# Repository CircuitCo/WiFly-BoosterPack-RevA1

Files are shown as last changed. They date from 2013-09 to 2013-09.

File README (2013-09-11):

The WiFly BoosterPack equips your Launchpad with the ability to connect to 802.11b/g wireless networks.  The design uses the Launchpad's UART hardware to interface to Roving Network's RN171XV ultra-low power embedded TCP/IP module.  An external antenna can be attached via a standard RP-SMA connector. Due to its small form factor and extremely low power consumption, it is perfect for mobile wireless applications such as asset monitoring, sensors, and portable battery operated devices. The WiFly BoosterPack is compatible with the MSP430 LaunchPad and Tiva C LaunchPad (previously Stellaris). This board is designed by Sakoman Inc. For more information on the designer please visit http://www.sakoman.com/.

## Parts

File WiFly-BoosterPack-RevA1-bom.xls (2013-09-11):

WIFLY BOOSTERPACK REV A1
QTY | REF DES | DESCRIPTION | PACKAGE | MAN | MAN P/N | VENDOR | VENDOR P/N
1 | R1 | RES 100K OHM 1/4W 5% CARBON FILM | thru-hole | STACKPOLE | CF14JT100K | DIGI-KEY | CF14JT100KTR-ND
2 | J1/3, J4/2 | 2.54 FEMALE HEADER DIP STRAIGHT HEIGHT=8.5MM 2X10 DIP=10.5mm GOLD | 2x10 0.1 thru-hole | MLE | SSHQ-110-D-08-F-LF
1 | J5 | CONN HEADER 8POS .100 STR 30AU | 2x4 0.1 thru-hole | FCI | 68602-108HLF | DIGI-KEY | 609-3362-ND
1 | U1 | WiFi / 802.11 Modules WIFI MOD FOR EXISTNG 802.15.4 W/ RP-SMA ANT | thru- hole | ROVING NETWORKS | RN-171-XV-S | MOUSER | 765-RN-XV-S
1 |  | PCB SI-10003 Rev A, 2 layers 0.062" FR4 1 oz copper, red SM, HASL

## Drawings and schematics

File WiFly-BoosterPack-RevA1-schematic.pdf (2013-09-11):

A

A

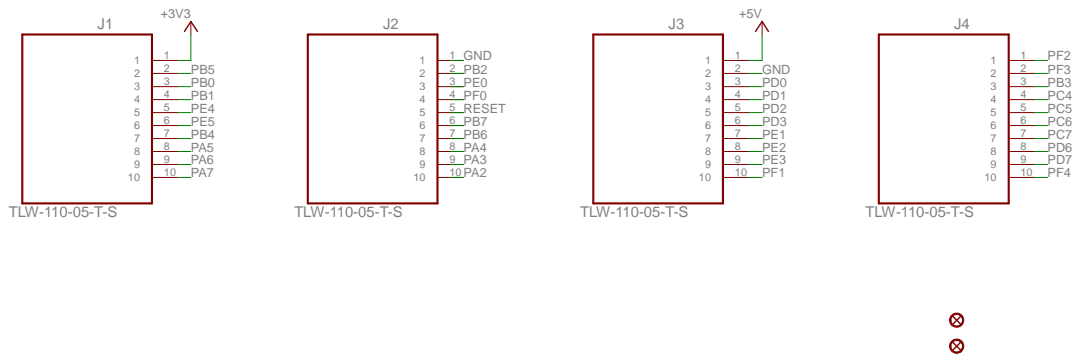
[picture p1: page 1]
TLW-110-05-T-S; GND; PE0 PF0 RESET PB7 PB6 PA4 PA3 PA2

A

A

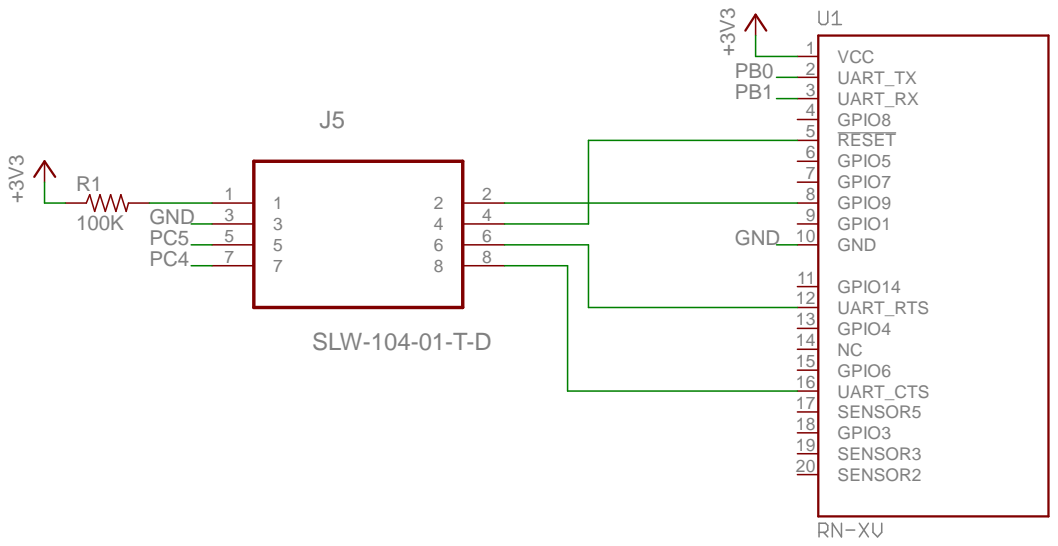
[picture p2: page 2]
SLW-104-01-T-D; VCC 1; GPIO5 6; RESET 5; GPIO7 7; UART_TX 2; GPIO8 4; GPIO9 8; GPIO3 18; UART_RTS 12; GPIO1 9; UART_RX 3; SENSOR5 17; GPIO14 11; GND 10; GPIO4 13 NC 14 GPIO6 15 UART_CTS 16; SENSOR3 19 SENSOR2 20; GND

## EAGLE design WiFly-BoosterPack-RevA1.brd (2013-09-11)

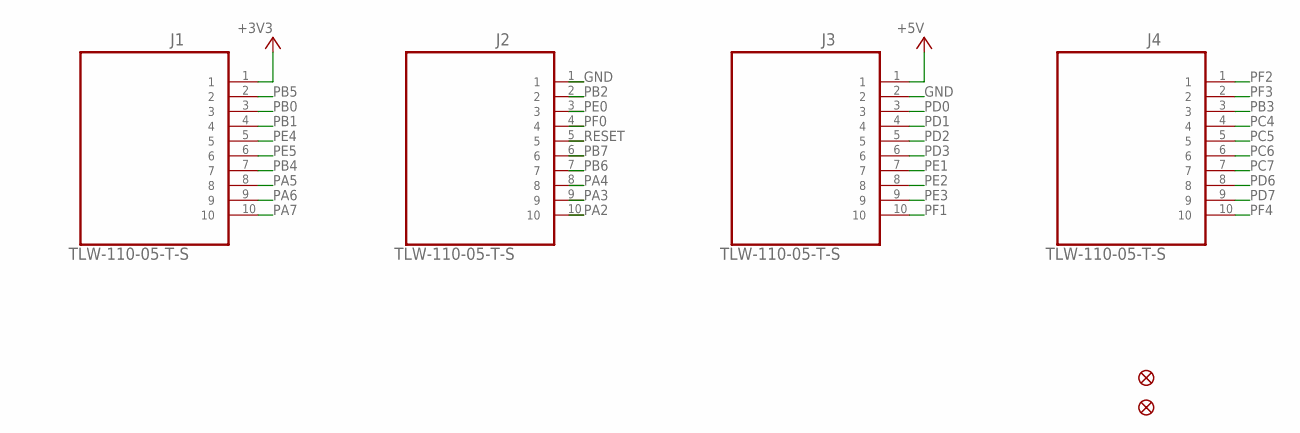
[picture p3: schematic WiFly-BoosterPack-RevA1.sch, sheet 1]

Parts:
FID1, FID2: FIDUCIAL1X2; FIDUCIAL-1X2
J1: TLW-110-05-T-S; SAMTEC_TLW-110-05-T-S
J2, J3, J4: TLW-110-05-T-S; SAMTEC_TLW-110-05-T-S; MPN TLW-110-05-T-S

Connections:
+3V3: J1.1; also elsewhere on the board
+5V: J3.1
GND: J2.1, J3.2; also elsewhere on the board
PA2: J2.10
PA3: J2.9
PA4: J2.8
PA5: J1.8
PA6: J1.9
PA7: J1.10
PB0: J1.3; also elsewhere on the board
PB1: J1.4; also elsewhere on the board
PB2: J2.2
PB3: J4.3
PB4: J1.7
PB5: J1.2
PB6: J2.7
PB7: J2.6
PC4: J4.4; also elsewhere on the board
PC5: J4.5; also elsewhere on the board
PC6: J4.6
PC7: J4.7
PD0: J3.3
PD1: J3.4
PD2: J3.5
PD3: J3.6
PD6: J4.8
PD7: J4.9
PE0: J2.3
PE1: J3.7
PE2: J3.8
PE3: J3.9
PE4: J1.5
PE5: J1.6
PF0: J2.4
PF1: J3.10
PF2: J4.1
PF3: J4.2
PF4: J4.10
RESET: J2.5

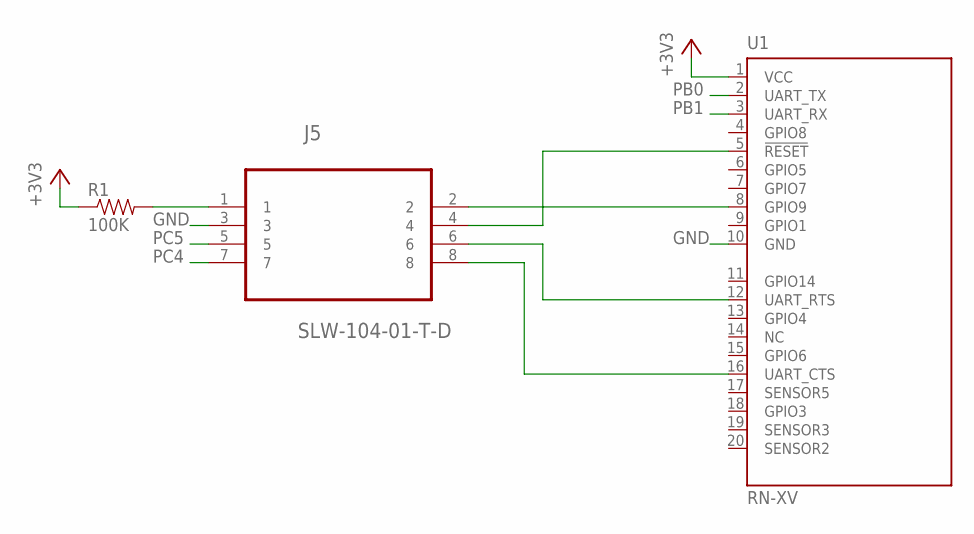
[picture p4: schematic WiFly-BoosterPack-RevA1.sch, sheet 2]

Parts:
J5: SLW-104-01-T-D; SAMTEC_SLW-104-01-T-D
R1: 100K; AXIAL-0.3
U1: RN-XV; RN-VX

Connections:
+3V3: R1.P$1 (1), U1.1 (VCC); also elsewhere on the board
GND: J5.3, U1.10 (GND); also elsewhere on the board
unnamed: J5.1, R1.P$2 (2)
unnamed: J5.2, U1.8 (GPIO9)
unnamed: J5.4, U1.5 (!RESET)
unnamed: J5.6, U1.12 (UART_RTS)
unnamed: J5.8, U1.16 (UART_CTS)
PB0: U1.2 (UART_TX); also elsewhere on the board
PB1: U1.3 (UART_RX); also elsewhere on the board
PC4: J5.7; also elsewhere on the board
PC5: J5.5; also elsewhere on the board

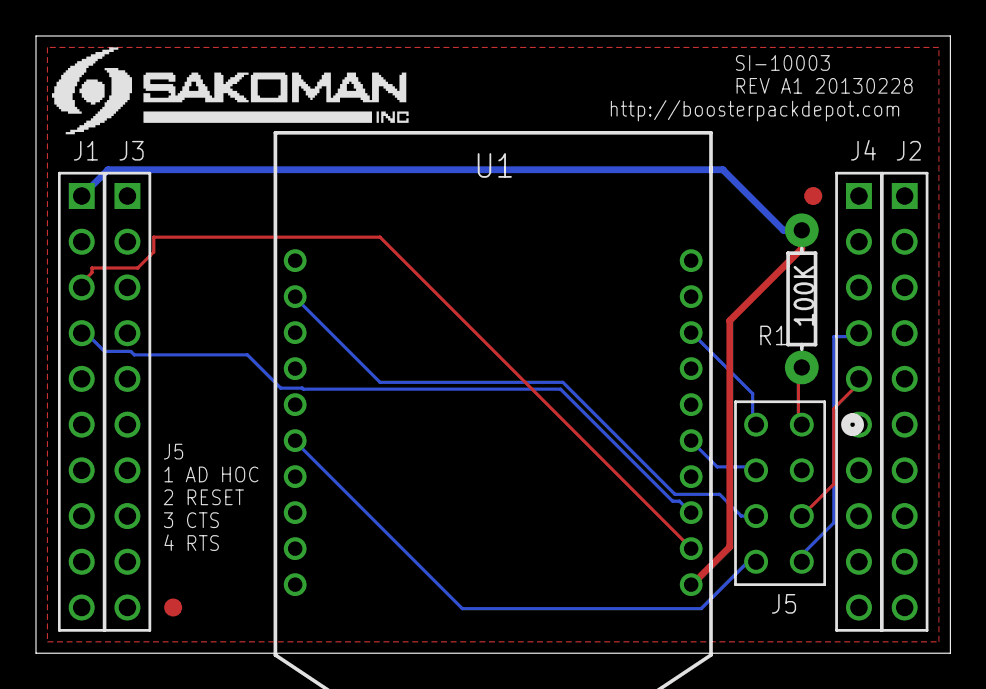
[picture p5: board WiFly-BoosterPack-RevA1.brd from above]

Board: 2 copper layers, 50.8 x 34.3 mm, 9 parts (0 on the bottom side), 11 nets.

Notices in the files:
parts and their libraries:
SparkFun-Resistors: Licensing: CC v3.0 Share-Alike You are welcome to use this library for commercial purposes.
